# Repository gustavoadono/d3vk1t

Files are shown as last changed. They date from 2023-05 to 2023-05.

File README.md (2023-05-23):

# **d3vkit board**
This repository contains information and resources related to a custom board featuring the STM32F412RET6 microcontroller. This board has been developed for study purposes and includes several integrated components, such as the LSM6DSMTR sensor (accelerometer and gyroscope), the HDC1080DMBR sensor (temperature and humidity), and the LPS22HBTR sensor (barometer). Additionally, the board features an SD card slot, CAN and RS485 interfaces, USB connectivity, and the ESP32-C3-WROOM-02-H4 module for Wi-Fi and Bluetooth communication.

<p align="center">
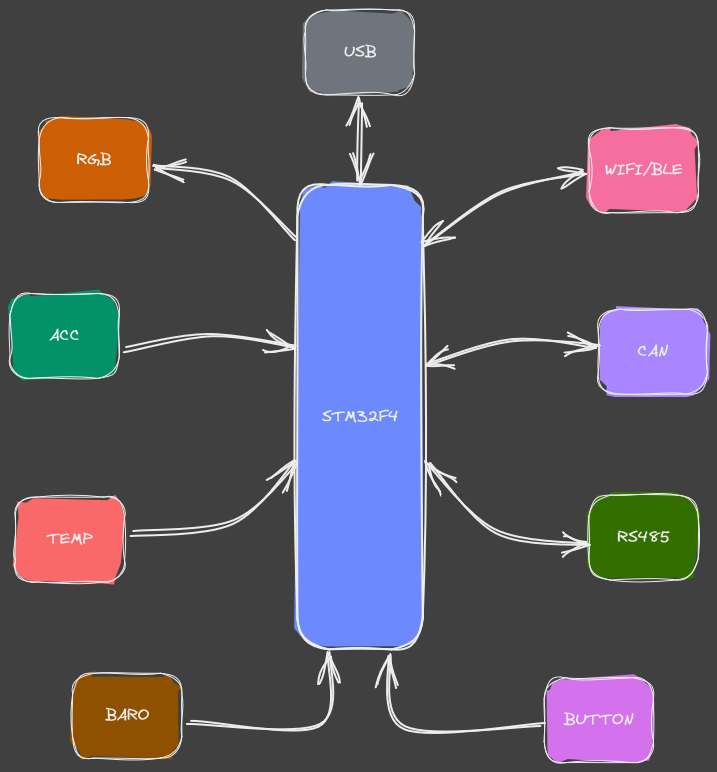
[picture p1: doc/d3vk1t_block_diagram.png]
diagram
  
</p>

# **overview**

The custom board has been designed to provide a flexible platform for studying and experimentation using the STM32F412RET6 microcontroller. It encompasses the following key features:

1. **STM32F412RET6 Microcontroller**: The STM32F412RET6 is a high-performance microcontroller based on the ARM Cortex-M4 architecture. It operates at a clock frequency of up to 100 MHz, with 512 KB of flash memory and 128 KB of RAM. This microcontroller offers advanced features, including peripheral interfaces, ADC, timers, and serial communication.

2. **LSM6DSMTR Sensor (Accelerometer and Gyroscope)**: The board integrates the LSM6DSMTR sensor, which combines a three-axis accelerometer and a three-axis gyroscope. This enables accurate motion detection, acceleration measurement, and inclination sensing.

3. **HDC1080DMBR Sensor (Temperature and Humidity)**: The board includes the HDC1080DMBR sensor, which provides precise temperature and humidity measurements in the surrounding environment. This feature is beneficial for projects involving climate monitoring or environmental control.

4. **LPS22HBTR Sensor (Barometer)**: The board incorporates the LPS22HBTR sensor, allowing atmospheric pressure measurements. This functionality proves useful for projects related to weather monitoring, altitude sensing, or flight control.

5. **SD Card Slot**: The board features an SD card slot, enabling read and write operations with removable memory cards. This facilitates data storage, such as measurement logs or configuration files.

6. **CAN and RS485 Interfaces**: The board incorporates circuits for CAN and RS485 interfaces, widely used in industrial applications for device communication. These interfaces ease integration within automation systems.

7. **USB Connectivity**: The board provides a USB port for communication with a computer or connection to other USB devices. This port supports data transfer and can power the board.

8. **ESP32-C3-WROOM-02-H4 Module (Wi-Fi and Bluetooth)**: The board includes the ESP32-C3-WROOM-02-H4 module, offering Wi-Fi and Bluetooth connectivity. This enables wireless communication, connection to Wi-Fi networks, and interaction with Bluetooth devices, making it suitable for IoT projects.

# **contact**

If you have any questions or need further information, feel free to get in touch. You can reach me via the provided email address in the repository's profile.

# bill of material

you can see the entire bill of materials through this link [d3vk1t-bom](https://gustavoadono.github.io/board/d3vk1t-bom).

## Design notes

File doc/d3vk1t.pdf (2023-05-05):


04/05/2023

d3vk1t Project
Configuration Report

## 1. Description

### 1.1. Project

Project Name | d3vk1t
Board Name | custom
Generated with: | STM32CubeMX 6.8.0
Date | 05/04/2023

### 1.2. MCU

MCU Series | STM32F4
MCU Line | STM32F412
MCU name | STM32F412RETx
MCU Package | LQFP64
MCU Pin number | 64

### 1.3. Core(s) information

Core(s) | Arm Cortex-M4

## 2. Pinout Configuration

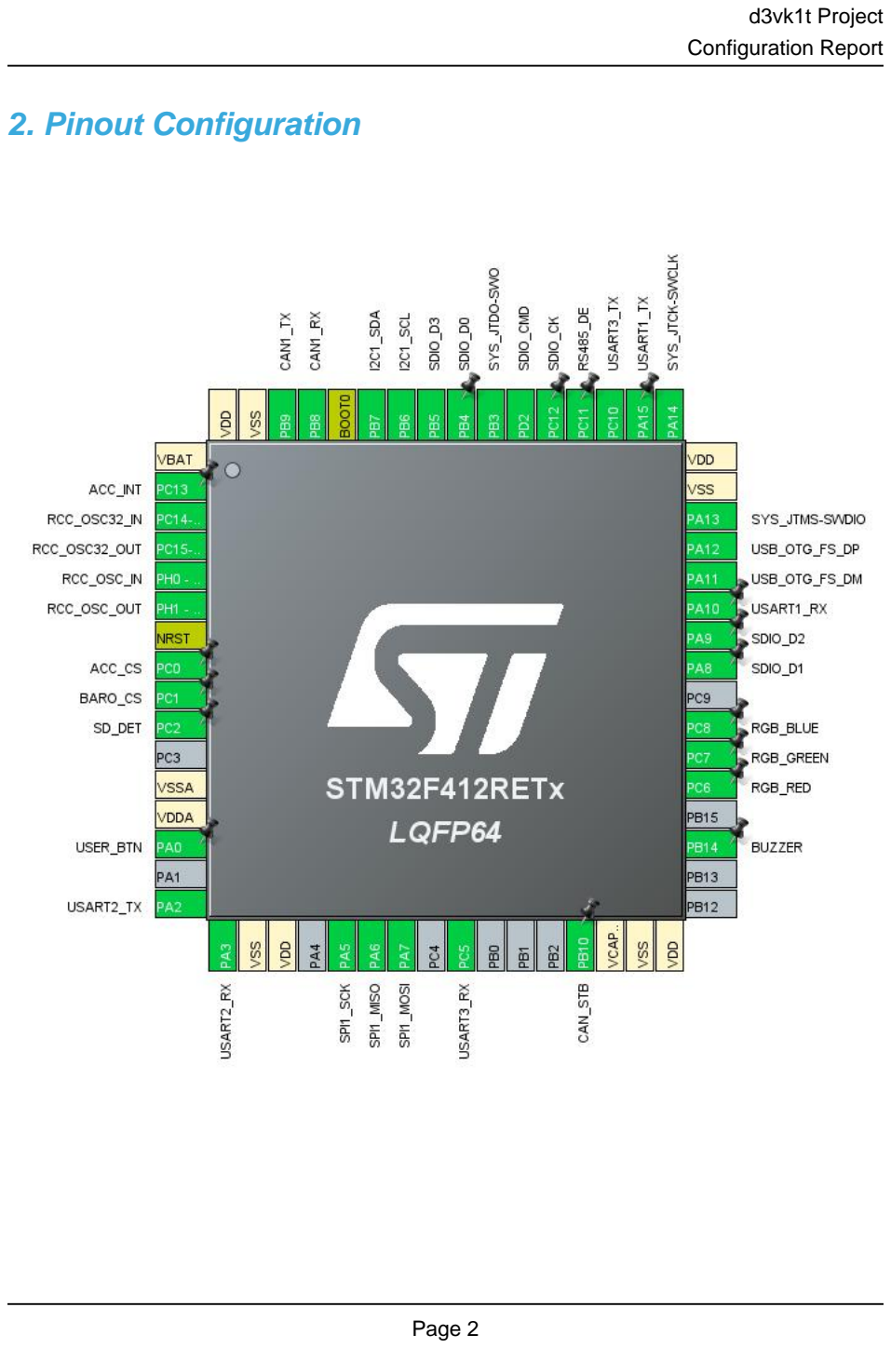
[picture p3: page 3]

## 3. Pins Configuration

Pin Number LQFP64 | Pin Name (function after reset) | Pin Type | Alternate Function(s) | Label
1 | VBAT | Power
2 | PC13 | I/O | GPIO_EXTI13 | ACC_INT
3 | PC14-OSC32_IN | I/O | RCC_OSC32_IN
4 | PC15-OSC32_OUT | I/O | RCC_OSC32_OUT
5 | PH0 - OSC_IN | I/O | RCC_OSC_IN
6 | PH1 - OSC_OUT | I/O | RCC_OSC_OUT
7 | NRST | Reset
8 | PC0 * | I/O | GPIO_Output | ACC_CS
9 | PC1 * | I/O | GPIO_Output | BARO_CS
10 | PC2 | I/O | GPIO_EXTI2 | SD_DET
12 | VSSA | Power
13 | VDDA | Power
14 | PA0 | I/O | GPIO_EXTI0 | USER_BTN
16 | PA2 | I/O | USART2_TX
17 | PA3 | I/O | USART2_RX
18 | VSS | Power
19 | VDD | Power
21 | PA5 | I/O | SPI1_SCK
22 | PA6 | I/O | SPI1_MISO
23 | PA7 | I/O | SPI1_MOSI
25 | PC5 | I/O | USART3_RX
29 | PB10 * | I/O | GPIO_Output | CAN_STB
30 | VCAP_1 | Power
31 | VSS | Power
32 | VDD | Power
35 | PB14 | I/O | TIM12_CH1 | BUZZER
37 | PC6 | I/O | TIM8_CH1 | RGB_RED
38 | PC7 | I/O | TIM8_CH2 | RGB_GREEN
39 | PC8 | I/O | TIM8_CH3 | RGB_BLUE
41 | PA8 | I/O | SDIO_D1
42 | PA9 | I/O | SDIO_D2
43 | PA10 | I/O | USART1_RX
44 | PA11 | I/O | USB_OTG_FS_DM
45 | PA12 | I/O | USB_OTG_FS_DP
46 | PA13 | I/O | SYS_JTMS-SWDIO
47 | VSS | Power

Pin Number LQFP64 | Pin Name (function after reset) | Pin Type | Alternate Function(s) | Label
48 | VDD | Power
49 | PA14 | I/O | SYS_JTCK-SWCLK
50 | PA15 | I/O | USART1_TX
51 | PC10 | I/O | USART3_TX
52 | PC11 * | I/O | GPIO_Output | RS485_DE
53 | PC12 | I/O | SDIO_CK
54 | PD2 | I/O | SDIO_CMD
55 | PB3 | I/O | SYS_JTDO-SWO
56 | PB4 | I/O | SDIO_D0
57 | PB5 | I/O | SDIO_D3
58 | PB6 | I/O | I2C1_SCL
59 | PB7 | I/O | I2C1_SDA
60 | BOOT0 | Boot
61 | PB8 | I/O | CAN1_RX
62 | PB9 | I/O | CAN1_TX
63 | VSS | Power
64 | VDD | Power

* The pin is affected with an I/O function

## 4. Clock Tree Configuration

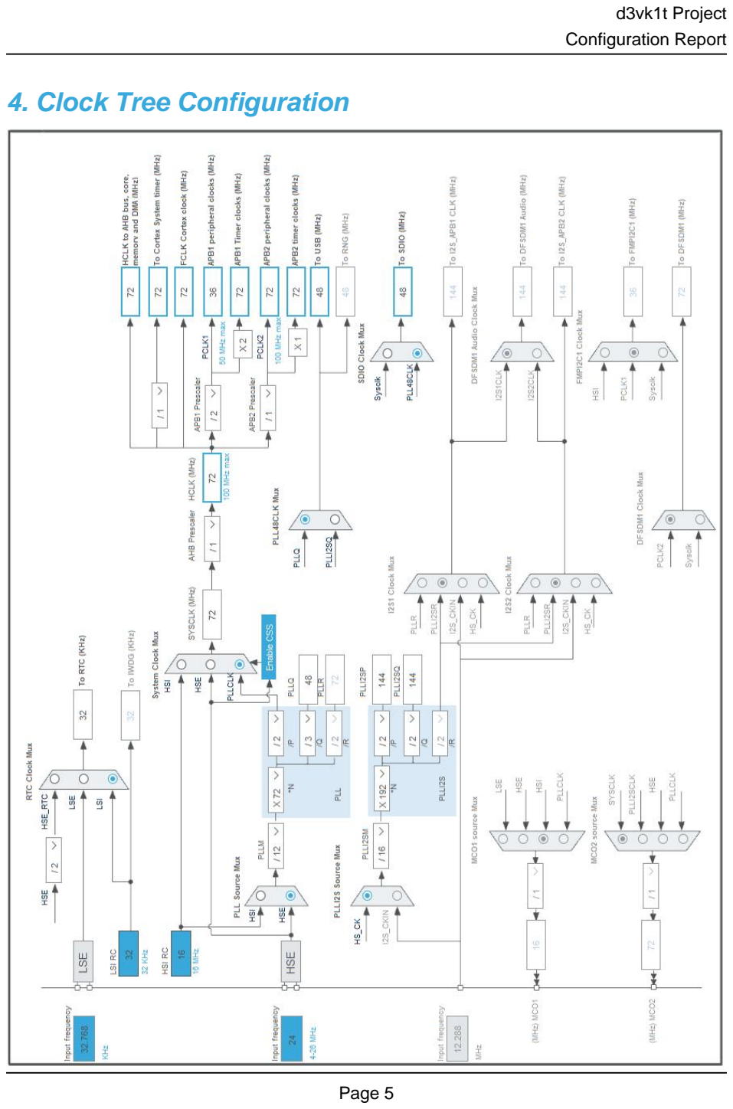
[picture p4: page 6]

## 5. Software Project

### 5.1. Project Settings

Name | Value
Project Name | d3vk1t
Project Folder | C:\dev\personal\hardware\d3vk1t\doc
Toolchain / IDE | EWARM V8.50
Firmware Package Name and Version | STM32Cube FW_F4 V1.27.1
Application Structure | Advanced
Generate Under Root | No
Do not generate the main() | No
Minimum Heap Size | 0x200
Minimum Stack Size | 0x400

### 5.2. Code Generation Settings

Name | Value
STM32Cube MCU packages and embedded software | Copy all used libraries into the project folder
Generate peripheral initialization as a pair of '.c/.h' files | No
Backup previously generated files when re-generating | No
Keep User Code when re-generating | Yes
Delete previously generated files when not re-generated | Yes
Set all free pins as analog (to optimize the power consumption) | No
Enable Full Assert | No

### 5.3. Advanced Settings - Generated Function Calls

Rank | Function Name | Peripheral Instance Name
1 | SystemClock_Config | RCC
2 | MX_GPIO_Init | GPIO
3 | MX_CAN1_Init | CAN1
4 | MX_I2C1_Init | I2C1
5 | MX_SDIO_SD_Init | SDIO
6 | MX_USART1_UART_Init | USART1
7 | MX_USART2_UART_Init | USART2
8 | MX_USB_OTG_FS_PCD_Init | USB_OTG_FS
9 | MX_RTC_Init | RTC
10 | MX_SPI1_Init | SPI1
11 | MX_TIM8_Init | TIM8

Rank | Function Name | Peripheral Instance Name
12 | MX_TIM12_Init | TIM12
13 | MX_USART3_UART_Init | USART3

## 6. Power Consumption Calculator report

### 6.1. Microcontroller Selection

Series | STM32F4
Line | STM32F412
MCU | STM32F412RETx
Datasheet | DS11139_Rev5

### 6.2. Parameter Selection

Temperature | 25
Vdd | 1.7

### 6.3. Battery Selection

Battery | Li-SOCL2(A3400)
Capacity | 3400.0 mAh
Self Discharge | 0.08 %/month
Nominal Voltage | 3.6 V
Max Cont Current | 100.0 mA
Max Pulse Current | 200.0 mA
Cells in series | 1
Cells in parallel | 1

### 6.4. Sequence

Step | Step1 | Step2
Mode | RUN | STOP
Vdd | 1.7 | 1.7
Voltage Source | Battery | Battery
Range | Scale1-High | No Scale
Fetch Type | FLASH | n/a
CPU Frequency | 100 MHz | 0 Hz
Clock Configuration | HSE PLL | Regulator_LPLV Flash-PwrDwn
Clock Source Frequency | 4 MHz | 0 Hz
Peripherals
Additional Cons. | 0 mA | 0 mA
Average Current | 21.7 mA | 18.5 µA
Duration | 0.1 ms | 0.9 ms
DMIPS | 125.0 | 0.0
Ta Max | 103.27 | 105
Category | In DS Table | In DS Table

### 6.5. Results

Sequence Time | 1 ms | Average Current | 2.19 mA
Battery Life | 2 months, 3 days, 20 hours | Average DMIPS | 125.0 DMIPS

### 6.6. Chart

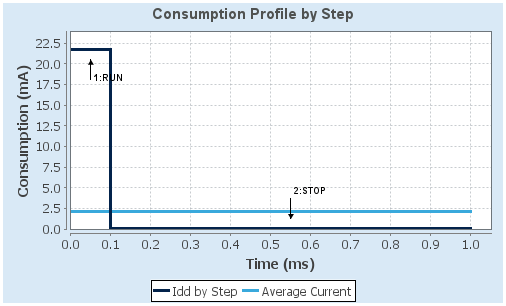
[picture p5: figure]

## 7. Peripherals and Middlewares Configuration

### 7.1. CAN1

mode: Activated
7.1.1. Parameter Settings:

Bit Timings Parameters:

Prescaler (for Time Quantum) | 16
Time Quantum | 444.44444444444446 *
Time Quanta in Bit Segment 1 | 1 Time
Time Quanta in Bit Segment 2 | 1 Time
Time for one Bit | 1333 *
Baud Rate | 749999 *
ReSynchronization Jump Width | 1 Time
Basic Parameters:
Time Triggered Communication Mode | Disable
Automatic Bus-Off Management | Disable
Automatic Wake-Up Mode | Disable
Automatic Retransmission | Disable
Receive Fifo Locked Mode | Disable
Transmit Fifo Priority | Disable
Advanced Parameters:
Operating Mode | Normal

### 7.2. I2C1

I2C: I2C
7.2.1. Parameter Settings:

Master Features:

I2C Speed Mode | Standard Mode
I2C Clock Speed (Hz) | 100000
Slave Features:
Clock No Stretch Mode | Disabled
Primary Address Length selection | 7-bit
Dual Address Acknowledged | Disabled
Primary slave address | 0
General Call address detection | Disabled

### 7.3. RCC

High Speed Clock (HSE): Crystal/Ceramic Resonator Low Speed Clock (LSE) : Crystal/Ceramic Resonator
7.3.1. Parameter Settings:

System Parameters:

VDD voltage (V) | 3.3
Instruction Cache | Enabled
Prefetch Buffer | Enabled
Data Cache | Enabled
Flash Latency(WS) | 2 WS (3 CPU cycle)
RCC Parameters:
HSI Calibration Value | 16
TIM Prescaler Selection | Disabled
HSE Startup Timout Value (ms) | 100
LSE Startup Timout Value (ms) | 5000
Power Parameters:
Power Regulator Voltage Scale | Power Regulator Voltage Scale 1

### 7.4. RTC

mode: Activate Clock Source
7.4.1. Parameter Settings:

General:

Hour Format | Hourformat 24
Asynchronous Predivider value | 127
Synchronous Predivider value | 255

### 7.5. SDIO

Mode: SD 4 bits Wide bus
7.5.1. Parameter Settings:

SDIO parameters:

Clock transition on which the bit capture is made Rising transition

SDIO Clock divider bypass | Disable
SDIO Clock output enable when the bus is idle | Disable the power save for the clock
SDIO hardware flow control | The hardware control flow is disabled
SDIOCLK clock divide factor | 0

### 7.6. SPI1

Mode: Full-Duplex Master
7.6.1. Parameter Settings:

Basic Parameters:

Frame Format | Motorola
Data Size | 8 Bits
First Bit | MSB First
Clock Parameters:
Prescaler (for Baud Rate) | 2
Baud Rate | 36.0 MBits/s *
Clock Polarity (CPOL) | Low
Clock Phase (CPHA) | 1 Edge
Advanced Parameters:
CRC Calculation | Disabled
NSS Signal Type | Software

### 7.7. SYS

Debug: Trace Asynchronous Sw Timebase Source: SysTick

### 7.8. TIM8

Channel1: PWM Generation CH1 Channel2: PWM Generation CH2 Channel3: PWM Generation CH3
7.8.1. Parameter Settings:

Counter Settings:

Prescaler (PSC - 16 bits value) | 0
Counter Mode | Up
Counter Period (AutoReload Register - 16 bits value ) | 65535

Internal Clock Division (CKD) | No Division
Repetition Counter (RCR - 8 bits value) | 0
auto-reload preload | Disable
Trigger Output (TRGO) Parameters:
Master/Slave Mode (MSM bit) | Disable (Trigger input effect not delayed)
Trigger Event Selection | Reset (UG bit from TIMx_EGR)
Break And Dead Time management - BRK Configuration:
BRK State | Disable
BRK Polarity | High
Break And Dead Time management - Output Configuration:
Automatic Output State | Disable
Off State Selection for Run Mode (OSSR) | Disable
Off State Selection for Idle Mode (OSSI) | Disable
Lock Configuration | Off
PWM Generation Channel 1:
Mode | PWM mode 1
Pulse (16 bits value) | 0
Output compare preload | Enable
Fast Mode | Disable
CH Polarity | High
CH Idle State | Reset
PWM Generation Channel 2:
Mode | PWM mode 1
Pulse (16 bits value) | 0
Output compare preload | Enable
Fast Mode | Disable
CH Polarity | High
CH Idle State | Reset
PWM Generation Channel 3:
Mode | PWM mode 1
Pulse (16 bits value) | 0
Output compare preload | Enable
Fast Mode | Disable
CH Polarity | High
CH Idle State | Reset

### 7.9. TIM12

Channel1: PWM Generation CH1
7.9.1. Parameter Settings:

Counter Settings:

Prescaler (PSC - 16 bits value) | 0
Counter Mode | Up
Counter Period (AutoReload Register - 16 bits value ) | 65535
Internal Clock Division (CKD) | No Division
auto-reload preload | Disable
PWM Generation Channel 1:
Mode | PWM mode 1
Pulse (16 bits value) | 0
Output compare preload | Enable
Fast Mode | Disable
CH Polarity | High

### 7.10. USART1

Mode: Asynchronous
7.10.1. Parameter Settings:

Basic Parameters:

Baud Rate | 115200
Word Length | 8 Bits (including Parity)
Parity | None
Stop Bits | 1
Advanced Parameters:
Data Direction | Receive and Transmit
Over Sampling | 16 Samples

### 7.11. USART2

Mode: Asynchronous
7.11.1. Parameter Settings:

Basic Parameters:

Baud Rate | 115200
Word Length | 8 Bits (including Parity)
Parity | None
Stop Bits | 1
Advanced Parameters:

Data Direction | Receive and Transmit
Over Sampling | 16 Samples

### 7.12. USART3

Mode: Asynchronous
7.12.1. Parameter Settings:

Basic Parameters:

Baud Rate | 115200
Word Length | 8 Bits (including Parity)
Parity | None
Stop Bits | 1
Advanced Parameters:
Data Direction | Receive and Transmit
Over Sampling | 16 Samples

### 7.13. USB_OTG_FS

Mode: Device_Only
7.13.1. Parameter Settings:
Speed | Full Speed 12MBit/s
Low power | Disabled
Battery charging | Disabled
Link Power Management | Disabled
VBUS sensing | Disabled
Signal start of frame | Disabled

* User modified value

## 8. System Configuration

### 8.1. GPIO configuration

IP | Pin | Signal | GPIO mode | GPIO pull/up pull down

Max
Speed

User Label

CAN1 | PB8 | CAN1_RX | Alternate Function Push Pull | No pull-up and no pull-down | Very High
*
| PB9 | CAN1_TX | Alternate Function Push Pull | No pull-up and no pull-down | Very High
*
I2C1 | PB6 | I2C1_SCL | Alternate Function Open Drain | No pull-up and no pull-down | Very High
*
| PB7 | I2C1_SDA | Alternate Function Open Drain | No pull-up and no pull-down | Very High
*
RCC | PC14- OSC32_IN | RCC_OSC32_IN | n/a | n/a | n/a
| PC15- OSC32_OU T | RCC_OSC32_O UT | n/a | n/a | n/a

PH0 -
OSC_IN
| | RCC_OSC_IN | n/a | n/a | n/a
| PH1 - OSC_OUT | RCC_OSC_OUT | n/a | n/a | n/a
SDIO | PA8 | SDIO_D1 | Alternate Function Push Pull | No pull-up and no pull-down | Very High
| PA9 | SDIO_D2 | Alternate Function Push Pull | No pull-up and no pull-down | Very High
| PC12 | SDIO_CK | Alternate Function Push Pull | No pull-up and no pull-down | Very High
| PD2 | SDIO_CMD | Alternate Function Push Pull | No pull-up and no pull-down | Very High
| PB4 | SDIO_D0 | Alternate Function Push Pull | No pull-up and no pull-down | Very High
| PB5 | SDIO_D3 | Alternate Function Push Pull | No pull-up and no pull-down | Very High
SPI1 | PA5 | SPI1_SCK | Alternate Function Push Pull | No pull-up and no pull-down | Very High
*
| PA6 | SPI1_MISO | Alternate Function Push Pull | No pull-up and no pull-down | Very High
*
| PA7 | SPI1_MOSI | Alternate Function Push Pull | No pull-up and no pull-down | Very High
*
SYS | PA13 | SYS_JTMS- SWDIO | n/a | n/a | n/a
| PA14 | SYS_JTCK- SWCLK | n/a | n/a | n/a
| PB3 | SYS_JTDO- SWO | n/a | n/a | n/a
TIM8 | PC6 | TIM8_CH1 | Alternate Function Push Pull | No pull-up and no pull-down | Low | RGB_RED

IP | Pin | Signal | GPIO mode | GPIO pull/up pull down | Max Speed | User Label
| PC7 | TIM8_CH2 | Alternate Function Push Pull | No pull-up and no pull-down | Low | RGB_GREEN
| PC8 | TIM8_CH3 | Alternate Function Push Pull | No pull-up and no pull-down | Low | RGB_BLUE
TIM12 | PB14 | TIM12_CH1 | Alternate Function Push Pull | No pull-up and no pull-down | Low | BUZZER
USART1 | PA10 | USART1_RX | Alternate Function Push Pull | No pull-up and no pull-down | Very High *
| PA15 | USART1_TX | Alternate Function Push Pull | No pull-up and no pull-down | Very High *
USART2 | PA2 | USART2_TX | Alternate Function Push Pull | No pull-up and no pull-down | Very High *
| PA3 | USART2_RX | Alternate Function Push Pull | No pull-up and no pull-down | Very High *
USART3 | PC5 | USART3_RX | Alternate Function Push Pull | No pull-up and no pull-down | Very High *
| PC10 | USART3_TX | Alternate Function Push Pull | No pull-up and no pull-down | Very High *
USB_OTG_ FS | PA11 | USB_OTG_FS_ DM | Alternate Function Push Pull | No pull-up and no pull-down | Very High *
| PA12 | USB_OTG_FS_ DP | Alternate Function Push Pull | No pull-up and no pull-down | Very High *
GPIO | PC13 | GPIO_EXTI13 | External Interrupt Mode with Rising edge trigger detection | No pull-up and no pull-down | n/a | ACC_INT
| PC0 | GPIO_Output | Output Push Pull | No pull-up and no pull-down | Low | ACC_CS
| PC1 | GPIO_Output | Output Push Pull | No pull-up and no pull-down | Low | BARO_CS
| PC2 | GPIO_EXTI2 | External Interrupt Mode with Rising edge trigger detection | No pull-up and no pull-down | n/a | SD_DET
| PA0 | GPIO_EXTI0 | External Interrupt Mode with Rising edge trigger detection | No pull-up and no pull-down | n/a | USER_BTN
| PB10 | GPIO_Output | Output Push Pull | No pull-up and no pull-down | Low | CAN_STB
| PC11 | GPIO_Output | Output Push Pull | No pull-up and no pull-down | Low | RS485_DE

### 8.2. DMA configuration

nothing configured in DMA service

### 8.3. NVIC configuration

8.3.1. NVIC
Interrupt Table | Enable | Preenmption Priority | SubPriority
Non maskable interrupt | true | 0 | 0
Hard fault interrupt | true | 0 | 0
Memory management fault | true | 0 | 0
Pre-fetch fault, memory access fault | true | 0 | 0
Undefined instruction or illegal state | true | 0 | 0
System service call via SWI instruction | true | 0 | 0
Debug monitor | true | 0 | 0
Pendable request for system service | true | 0 | 0
System tick timer | true | 15 | 0
PVD interrupt through EXTI line 16 | | unused
Flash global interrupt | | unused
RCC global interrupt | | unused
EXTI line0 interrupt | | unused
EXTI line2 interrupt | | unused
CAN1 TX interrupts | | unused
CAN1 RX0 interrupts | | unused
CAN1 RX1 interrupt | | unused
CAN1 SCE interrupt | | unused
I2C1 event interrupt | | unused
I2C1 error interrupt | | unused
SPI1 global interrupt | | unused
USART1 global interrupt | | unused
USART2 global interrupt | | unused
USART3 global interrupt | | unused
EXTI line[15:10] interrupts | | unused
TIM8 break interrupt and TIM12 global interrupt | | unused
TIM8 update interrupt and TIM13 global interrupt | | unused
TIM8 trigger and commutation interrupts and TIM14 global interrupt | | unused
TIM8 capture compare interrupt | | unused
SDIO global interrupt | | unused
USB On The Go FS global interrupt | | unused
FPU global interrupt | | unused
8.3.2. NVIC Code generation
Enabled interrupt Table | Select for init | Generate IRQ | Call HAL handler

Enabled interrupt Table | Select for init sequence ordering | Generate IRQ handler | Call HAL handler
Non maskable interrupt | false | true | false
Hard fault interrupt | false | true | false
Memory management fault | false | true | false
Pre-fetch fault, memory access fault | false | true | false
Undefined instruction or illegal state | false | true | false
System service call via SWI instruction | false | true | false
Debug monitor | false | true | false
Pendable request for system service | false | true | false
System tick timer | false | true | true

* User modified value

## 9. System Views

9.1. Category view
9.1.1. Current

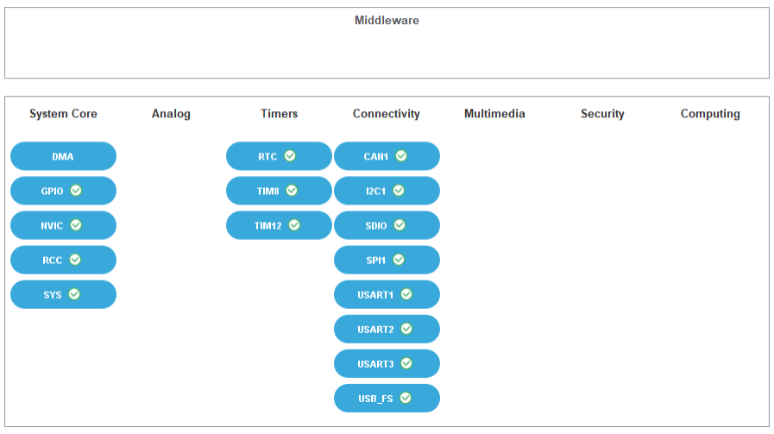
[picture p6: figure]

## 10. Docs & Resources

Type | Link
BSDL files | https://www.st.com/resource/en/bsdl_model/stm32f412_bsdl.zip
IBIS models | https://www.st.com/resource/en/ibis_model/stm32f412_ibis.zip
System View Description | https://www.st.com/resource/en/svd/stm32f4_svd.zip
BSDL files | https://www.st.com/resource/en/bsdl_model/stm32f412_bsdl.zip
IBIS models | https://www.st.com/resource/en/ibis_model/stm32f412_ibis.zip
System View Description | https://www.st.com/resource/en/svd/stm32f4_svd.zip
Presentations | https://www.st.com/resource/en/product_presentation/stm32-stm8_embedded_software_solutions.pdf
Presentations | https://www.st.com/resource/en/product_presentation/stm32_eval-tools_portfolio.pdf
Presentations | https://www.st.com/resource/en/product_presentation/stm32_stm8_functi onal-safety-packages.pdf
Presentations | https://www.st.com/resource/en/product_presentation/stm32-stm8_software_development_tools.pdf
Training Material | https://www.st.com/resource/en/sales_guide/sg_sc2154.pdf
Flyers | https://www.st.com/resource/en/flyer/flstm32f4x1.pdf
Flyers | https://www.st.com/resource/en/flyer/flstm32nucleo.pdf
Flyers | https://www.st.com/resource/en/flyer/flstmcsuite.pdf
Flyers | https://www.st.com/resource/en/flyer/flstm32trust.pdf
Product Certifications | https://www.st.com/resource/en/certification_document/stm32_authentication_can.pdf
Application Notes | https://www.st.com/resource/en/application_note/an1181-electrostatic-discharge-sensitivity-measurement-stmicroelectronics.pdf
Application Notes | https://www.st.com/resource/en/application_note/an1709-emc-design-guide-for-stm8-stm32-and-legacy-mcus-stmicroelectronics.pdf
Application Notes | https://www.st.com/resource/en/application_note/an2606-stm32-

| microcontroller-system-memory-boot-mode-stmicroelectronics.pdf
Application Notes | https://www.st.com/resource/en/application_note/an2639-soldering-recommendations-and-package-information-for-leadfree-ecopack-mcus-and-mpus-stmicroelectronics.pdf
Application Notes | https://www.st.com/resource/en/application_note/an2834-how-to-get-the-best-adc-accuracy-in-stm32-microcontrollers-stmicroelectronics.pdf
Application Notes | https://www.st.com/resource/en/application_note/an2867-oscillator-design-guide-for-stm8afals-stm32-mcus-and-mpus-stmicroelectronics.pdf
Application Notes | https://www.st.com/resource/en/application_note/an2945-stm8s-and-stm32-mcus-a-consistent-832bit-product-line-for-painless-migration-stmicroelectronics.pdf
Application Notes | https://www.st.com/resource/en/application_note/an3070-managing-the-driver-enable-signal-for-rs485-and-iolink-communications-with-the-stm32s-usart-stmicroelectronics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
Application Notes | https://www.st.com/resource/en/application_note/an3126-audio-and-waveform-generation-using-the-dac-in-stm32-products-stmicroelectronics.pdf
Application Notes | https://www.st.com/resource/en/application_note/an3154-can-protocol-used-in-the-stm32-bootloader-stmicroelectronics.pdf
Application Notes | https://www.st.com/resource/en/application_note/an3155-usart-protocol-used-in-the-stm32-bootloader-stmicroelectronics.pdf
Application Notes | https://www.st.com/resource/en/application_note/an3156-usb-dfu-protocol-used-in-the-stm32-bootloader-stmicroelectronics.pdf
Application Notes | https://www.st.com/resource/en/application_note/an3364-migration-and-compatibility-guidelines-for-stm32-microcontroller-applications-stmicroelectronics.pdf
Application Notes | https://www.st.com/resource/en/application_note/an3997-audio-playback-and-recording-using-the-stm32f4discovery-stmicroelectronics.pdf
Application Notes | https://www.st.com/resource/en/application_note/an3998-pdm-audio-software-decoding-on-stm32-microcontrollers-stmicroelectronics.pdf
Application Notes | https://www.st.com/resource/en/application_note/an4013-stm32-crossseries-timer-overview-stmicroelectronics.pdf
Application Notes | https://www.st.com/resource/en/application_note/an4031-using-the-

| stm32f2-stm32f4-and-stm32f7-series-dma-controller-stmicroelectronics.pdf
Application Notes | https://www.st.com/resource/en/application_note/an4221-i2c-protocol-used-in-the-stm32-bootloader-stmicroelectronics.pdf
Application Notes | https://www.st.com/resource/en/application_note/an4229-how-to-implement-a-vocoder-solution-using-stm32-microcontrollers-stmicroelectronics.pdf
Application Notes | https://www.st.com/resource/en/application_note/an4230-stm32-microcontroller-random-number-generation-validation-using-the-nist-statistical-test-suite-stmicroelectro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
Application Notes | https://www.st.com/resource/en/application_note/an4277-using-stm32-device-pwm-shutdown-features-for-motor-control-and-digital-power-conversion-stmicroelectronics.pdf
Application Notes | https://www.st.com/resource/en/application_note/an4286-spi-protocol-used-in-the-stm32-bootloader-stmicroelectronics.pdf
Application Notes | https://www.st.com/resource/en/application_note/an4488-getting-started-with-stm32f4xxxx-mcu-hardware-development-stmicroelectronics.pdf
Application Notes | https://www.st.com/resource/en/application_note/an4566-extending-the-dac-performance-of-stm32-microcontrollers-stmicroelectronics.pdf
Application Notes | https://www.st.com/resource/en/application_note/an4655-virtually-increasing-the-number-of-serial-communication-peripherals-in-stm32-applications-stmicroelectronics.p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
Application Notes | https://www.st.com/resource/en/application_note/an4739-stm32cube-firmware-examples-for-stm32f4-series-stmicroelectronics.pdf
Application Notes | https://www.st.com/resource/en/application_note/an4750-handling-of-soft-errors-in-stm32-applications-stmicroelectronics.pdf
Application Notes | https://www.st.com/resource/en/application_note/an4759-using-the-hardware-realtime-clock-rtc-and-the-tamper-management-unit-tamp-with-stm32-microcontrollers-stmicroe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
Application Notes | https://www.st.com/resource/en/application_note/an4776-generalpurpose-timer-cookbook-for-stm32-microcontrollers-stmicroelectronics.pdf
Application Notes | https://www.st.com/resource/en/application_note/an4803-highspeed-si- simulations-using-ibis-and-boardlevel-simulations-using-hyperlynx-si-on-

| stm32-mcus-and-mpus-stmicroelectronics.pdf
Application Notes | https://www.st.com/resource/en/application_note/an4838-managing-memory-protection-unit-in-stm32-mcus-stmicroelectronics.pdf
Application Notes | https://www.st.com/resource/en/application_note/an4850-stm32-mcus-spreadspectrum-clock-generation-principles-properties-and-implementation-stmicroelectronics.pdf
Application Notes | https://www.st.com/resource/en/application_note/an4879-usb-hardware-and-pcb-guidelines-using-stm32-mcus-stmicroelectronics.pdf
Application Notes | https://www.st.com/resource/en/application_note/an4904-migration-of-microcontroller-applications-from-stm32f1-series-to-stm32f4-access-lines-stmicroelectronics.pdf
Application Notes | https://www.st.com/resource/en/application_note/an4908-stm32-usart-automatic-baud-rate-detection-stmicroelectronics.pdf
Application Notes | https://www.st.com/resource/en/application_note/an4989-stm32-microcontroller-debug-toolbox-stmicroelectronics.pdf
Application Notes | https://www.st.com/resource/en/application_note/an4990-getting-started-with-sigmadelta-digital-interface-on-applicable-stm32-microcontrollers-stmicroelectronics.pdf
Application Notes | https://www.st.com/resource/en/application_note/an4995-using-an-electromyogram-technique-to-detect-muscle-activity-stmicroelectronics.pdf
Application Notes | https://www.st.com/resource/en/application_note/an5027-interfacing-pdm-digital-microphones-using-stm32-mcus-and-mpus-stmicroelectronics.pdf
Application Notes | https://www.st.com/resource/en/application_note/an5036-thermal-management-guidelines-for-stm32-applications-stmicroelectronics.pdf
Application Notes | https://www.st.com/resource/en/application_note/an5073-receiving-spdif-audio-stream-with-the-stm32f4f7h7-series-stmicroelectronics.pdf
Application Notes | https://www.st.com/resource/en/application_note/an5225-usb-typec-power-delivery-using-stm32-mcus-and-mpus-stmicroelectronics.pdf
Application Notes | https://www.st.com/resource/en/application_note/an5543-enhanced-methods-to-handle-spi-communication-on-stm32-devices-stmicroelectronics.pdf
Application Notes | https://www.st.com/resource/en/application_note/an4760-quadspi-

| interface-on-stm32-microcontrollers-and-microprocessors--stmicroelectronics.pdf
Application Notes | https://www.st.com/resource/en/application_note/an4899-stm32-microcontroller-gpio-hardware-settings-and-lowpower-consumption-stmicroelectronics.pdf
Application Notes | https://www.st.com/resource/en/application_note/an5612-esd-protection-of-stm32-mcus-and-mpus-stmicroelectronics.pdf
Application Notes | https://www.st.com/resource/en/application_note/an5156-introduction-to-stm32-microcontrollers-security-stmicroelectronics.pdf
Application Notes for related Tools & Software | https://www.st.com/resource/en/application_note/an1202_freertos_guide-freertos-guide-stmicroelectronics.pdf
Application Notes for related Tools & Software | https://www.st.com/resource/en/application_note/an1602_semihosting_in_truestudio-how-to-do-semihosting-in-truestudio-stmicroelectronics.pdf
Application Notes for related Tools & Software | https://www.st.com/resource/en/application_note/an1801_stm32cubeprogrammer_in_truestudio-installing-stm32cubeprogrammer-in-truestudio-stmicroelectronics.pdf
Application Notes for related Tools & Software | https://www.st.com/resource/en/application_note/atollic_editing_keyboard_shortcuts-atollic-editing-keyboard-shortcuts-stmicroelectronics.pdf
Application Notes for related Tools & Software | https://www.st.com/resource/en/application_note/iar_to_atollic_truestudio_migration_guide-truestudio-for-arm-migration-guide-iar-embedded-workbench-to-truestudio-stm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
Application Notes for related Tools & Software | https://www.st.com/resource/en/application_note/stm32cubemx_installation_in_truestudio-stm32cubemx-installation-in-truestudio-stmicroelectronics.pdf
Application Notes for related Tools & Software | https://www.st.com/resource/en/application_note/an2656-stm32f10xxx-lcd-glass-driver-firmware-stmicroelectronics.pdf
Application Notes for related Tools & Software | https://www.st.com/resource/en/application_note/an2790-tft-lcd-interfacing-with-the-highdensity-stm32f10xxx-fsmc-stmicroelectronics.pdf
Application Notes | https://www.st.com/resource/en/application_note/an3078-stm32-

for related Tools & Software | inapplication-programming-over-the-ic-bus-stmicroelectronics.pdf
Application Notes for related Tools & Software | https://www.st.com/resource/en/application_note/an3116-stm32s-adc-modes-and-their-applications-stmicroelectronics.pdf
Application Notes for related Tools & Software | https://www.st.com/resource/en/application_note/an3174-implementing-receivers-for-infrared-remote-control-protocols-using-stm32f10xxx-microcontrollers-stmicroelectro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
Application Notes for related Tools & Software | https://www.st.com/resource/en/application_note/an3241-qvga-tftlcd-direct-drive-using-the-stm32f10xx-fsmc-peripheral-stmicroelectronics.pdf
Application Notes for related Tools & Software | https://www.st.com/resource/en/application_note/an3307-guidelines-for-obtaining-iec-60335-class-b-certification-for-any-stm32-application-stmicroelectronics.pdf
Application Notes for related Tools & Software | https://www.st.com/resource/en/application_note/an3364-migration-and-compatibility-guidelines-for-stm32-microcontroller-applications-stmicroelectronics.pdf
Application Notes for related Tools & Software | https://www.st.com/resource/en/application_note/an3965-stm32f40xstm32f41x-inapplication-programming-using-the-usart-stmicroelectronics.pdf
Application Notes for related Tools & Software | https://www.st.com/resource/en/application_note/an3969-eeprom-emulation-in-stm32f40xstm32f41x-microcontrollers-stmicroelectronics.pdf
Application Notes for related Tools & Software | https://www.st.com/resource/en/application_note/an3990-upgrading-stm32f4discovery-board-firmware-using-a-usb-key-stmicroelectronics.pdf
Application Notes for related Tools & Software | https://www.st.com/resource/en/application_note/an3997-audio-playback-and-recording-using-the-stm32f4discovery-stmicroelectronics.pdf
Application Notes for related Tools & Software | https://www.st.com/resource/en/application_note/an3998-pdm-audio-software-decoding-on-stm32-microcontrollers-stmicroelectronics.pdf

Application Notes
for related Tools

https://www.st.com/resource/en/application_note/an4044-floating-pointunit-demonstration-on-stm32-microcontrollers-stmicroelectronics.pdf

& Software
Application Notes for related Tools & Software | https://www.st.com/resource/en/application_note/an4323-getting-started-with-stemwin-library-stmicroelectronics.pdf
Application Notes for related Tools & Software | https://www.st.com/resource/en/application_note/an4435-guidelines-for-obtaining-ulcsaiec-607301603351-class-b-certification-in-any-stm32-application-stmicroelectroni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
Application Notes for related Tools & Software | https://www.st.com/resource/en/application_note/an4457-implementing-an-emulated-uart-on-stm32f4-microcontrollers-stmicroelectronics.pdf
Application Notes for related Tools & Software | https://www.st.com/resource/en/application_note/an4499-stm32--nrf51822-bluetooth-low-energy-system-solution-stmicroelectronics.pdf
Application Notes for related Tools & Software | https://www.st.com/resource/en/application_note/an4502-stm32-smbuspmbus-embedded-software-expansion-for-stm32cube-stmicroelectronics.pdf
Application Notes for related Tools & Software | https://www.st.com/resource/en/application_note/an4515-using-batch-acquisition-mode-bam-to-maximize-power-efficiency-on-stm32f410-stm32f411-stm32f412-stm32f413-micro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
Application Notes for related Tools & Software | https://www.st.com/resource/en/application_note/an4657-stm32-inapplication-programming-iap-using-the-usart-stmicroelectronics.pdf
Application Notes for related Tools & Software | https://www.st.com/resource/en/application_note/an4666-parallel-synchronous-transmission-using-gpio-and-dma-stmicroelectronics.pdf
Application Notes for related Tools & Software | https://www.st.com/resource/en/application_note/an4678-full-duplex-spi-emulation-for-stm32f4-microcontrollers-stmicroelectronics.pdf
Application Notes for related Tools & Software | https://www.st.com/resource/en/application_note/an4701-proprietary-code-readout-protection-on-microcontrollers-of-the-stm32f4-series-stmicroelectronics.pdf

Application Notes
for related Tools

https://www.st.com/resource/en/application_note/an4739-stm32cubefirmware-examples-for-stm32f4-series-stmicroelectronics.pdf

& Software
Application Notes for related Tools & Software | https://www.st.com/resource/en/application_note/an4758-proprietary-code-readout-protection-on-stm32l4-stm32l4-stm32g4-and-stm32wb-series-mcus-stmicroelectronics.pdf
Application Notes for related Tools & Software | https://www.st.com/resource/en/application_note/an4759-using-the-hardware-realtime-clock-rtc-and-the-tamper-management-unit-tamp-with-stm32-microcontrollers-stmicroe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
Application Notes for related Tools & Software | https://www.st.com/resource/en/application_note/an4841-digital-signal-processing-for-stm32-microcontrollers-using-cmsis-stmicroelectronics.pdf
Application Notes for related Tools & Software | https://www.st.com/resource/en/application_note/an4968-proprietary-code-read-out-protection-pcrop-on-stm32f72xxx-and-stm32f73xxx-microcontrollers-stmicroelectronics.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
Application Notes for related Tools & Software | https://www.st.com/resource/en/application_note/an5054-secure-programming-using-stm32cubeprogrammer-stmicroelectronics.pdf
Application Notes for related Tools & Software | https://www.st.com/resource/en/application_note/an5056-integration-guide-for-the-xcubesbsfu-stm32cube-expansion-package-stmicroelectronics.pdf
Application Notes for related Tools & Software | https://www.st.com/resource/en/application_note/an5360-getting-started-with-projects-based-on-the-stm32mp1-series-in-stm32cubeide-stmicroelectronics.pdf
Application Notes for related Tools & Software | https://www.st.com/resource/en/application_note/an5361-getting-started-with-projects-based-on-dualcore-stm32h7-microcontrollers-in-stm32cubeide-stmicroelectronics.pd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
Application Notes for related Tools & Software | https://www.st.com/resource/en/application_note/an5394-getting-started-with-projects-based-on-the-stm32l5-series-in-stm32cubeide-stmicroelectronics.pdf
Application Notes for related Tools & Software | https://www.st.com/resource/en/application_note/an5418-how-to-build-a-simple-usbpd-sink-application-with-stm32cubemx-stmicroelectronics.pdf
Application Notes for related Tools & Software | https://www.st.com/resource/en/application_note/an5426-migrating-graphics-middleware-projects-from-stm32cubemx-540-to-stm32cubemx-550-stmicroelectronics.pdf

Application Notes for related Tools & Software | https://www.st.com/resource/en/application_note/an5464-position-control-of-a-threephase-permanent-magnet-motor-using-xcubemcsdk-or-xcubemcsdkful-stmicroelectronics.p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
Application Notes for related Tools & Software | https://www.st.com/resource/en/application_note/an5564-getting-started-with-projects-based-on-dualcore-stm32wl-microcontrollers-in-stm32cubeide-stmicroelectronics.pd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
Application Notes for related Tools & Software | https://www.st.com/resource/en/application_note/an5698-adapting-the-xcubestl-functional-safety-package-for-stm32-iec-61508-compliant-to-other-safety-standards-stmicr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
Application Notes for related Tools & Software | https://www.st.com/resource/en/application_note/an5731-stm32cubemx-and-stm32cubeide-threadsafe-solution-stmicroelectronics.pdf
Design Notes & Tips | https://www.st.com/resource/en/design_tip/dt0117-microphone-array-beamforming-in-the-pcm-and-pdm-domain-stmicroelectronics.pdf
Device Option Lists | https://www.st.com/resource/en/device_option_list/opl_stm32f412_1m.zip
Errata Sheets | https://www.st.com/resource/en/errata_sheet/es0305-stm32f412xexg-device-limitations-stmicroelectronics.pdf
Datasheet | https://www.st.com/resource/en/datasheet/dm00213872.pdf
Data brief | https://www.st.com/resource/en/data_brief/dm00166585.pdf
Programming Manuals | https://www.st.com/resource/en/programming_manual/pm0214-stm32-cortexm4-mcus-and-mpus-programming-manual-stmicroelectronics.pdf
Reference Manuals | https://www.st.com/resource/en/reference_manual/rm0402-stm32f412-advanced-armbased-32bit-mcus-stmicroelectronics.pdf
Technical Notes & Articles | https://www.st.com/resource/en/technical_note/tn0516-overview-of-the-stm32f0xf100xxf103xx-and-stm32f2xxf30xf4xx-mcus-pmsm-singledual-foc-sdk-v40-stmicroelectronics.p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
Technical Notes & Articles | https://www.st.com/resource/en/technical_note/tn1163-description-of-wlcsp-for-microcontrollers-and-recommendations-for-its-use-stmicroelectronics.pdf
Technical Notes & Articles | https://www.st.com/resource/en/technical_note/tn1204-tape-and-reel-shipping-media-for-stm32-microcontrollers-in-bga-packages-stmicroelectronics.pdf

Technical Notes & Articles | https://www.st.com/resource/en/technical_note/tn1205-tape-and-reel-shipping-media-for-stm8-and-stm32-microcontrollers-in-fpn-packages-stmicroelectronics.pdf
Technical Notes & Articles | https://www.st.com/resource/en/technical_note/tn1206-tape-and-reel-shipping-media-for-stm8-and-stm32-microcontrollers-in-qfp-packages-stmicroelectronics.pdf
Technical Notes & Articles | https://www.st.com/resource/en/technical_note/tn1207-tape-and-reel-shipping-media-for-stm8-and-stm32-microcontrollers-in-so-packages-stmicroelectronics.pdf
Technical Notes & Articles | https://www.st.com/resource/en/technical_note/tn1208-tape-and-reel-shipping-media-for-stm8-and-stm32-microcontrollers-in-tssop-and-ssop-packages-stmicroelectronics.p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
Technical Notes & Articles | https://www.st.com/resource/en/technical_note/tn1433-reference-device-marking-schematics-for-stm32-microcontrollers-and-microprocessors-stmicroelectronics.pdf

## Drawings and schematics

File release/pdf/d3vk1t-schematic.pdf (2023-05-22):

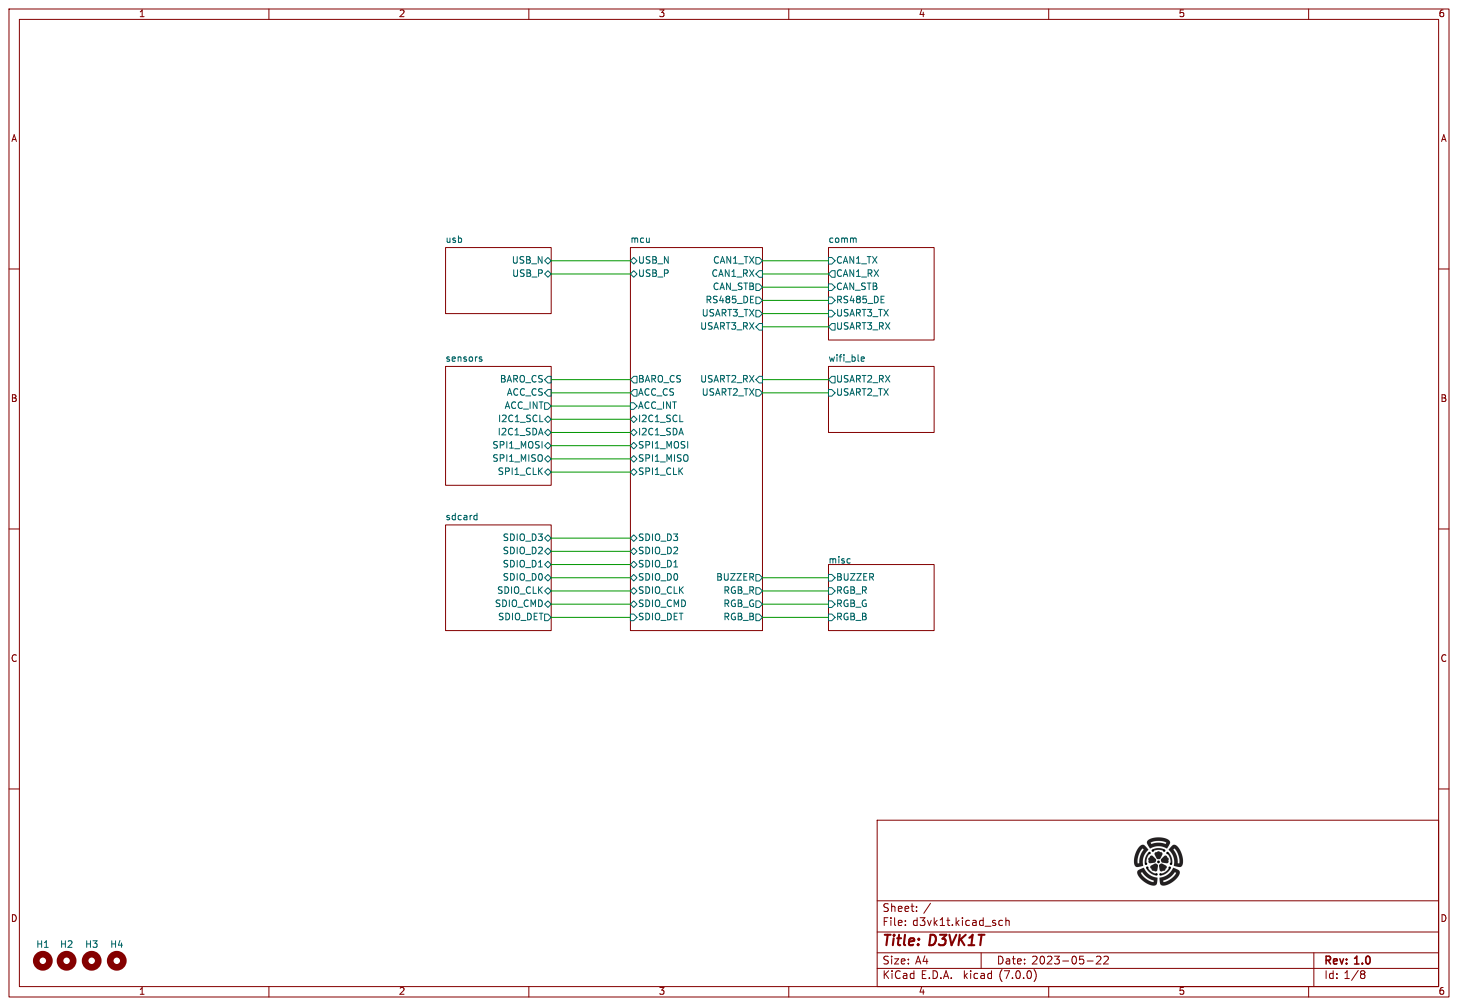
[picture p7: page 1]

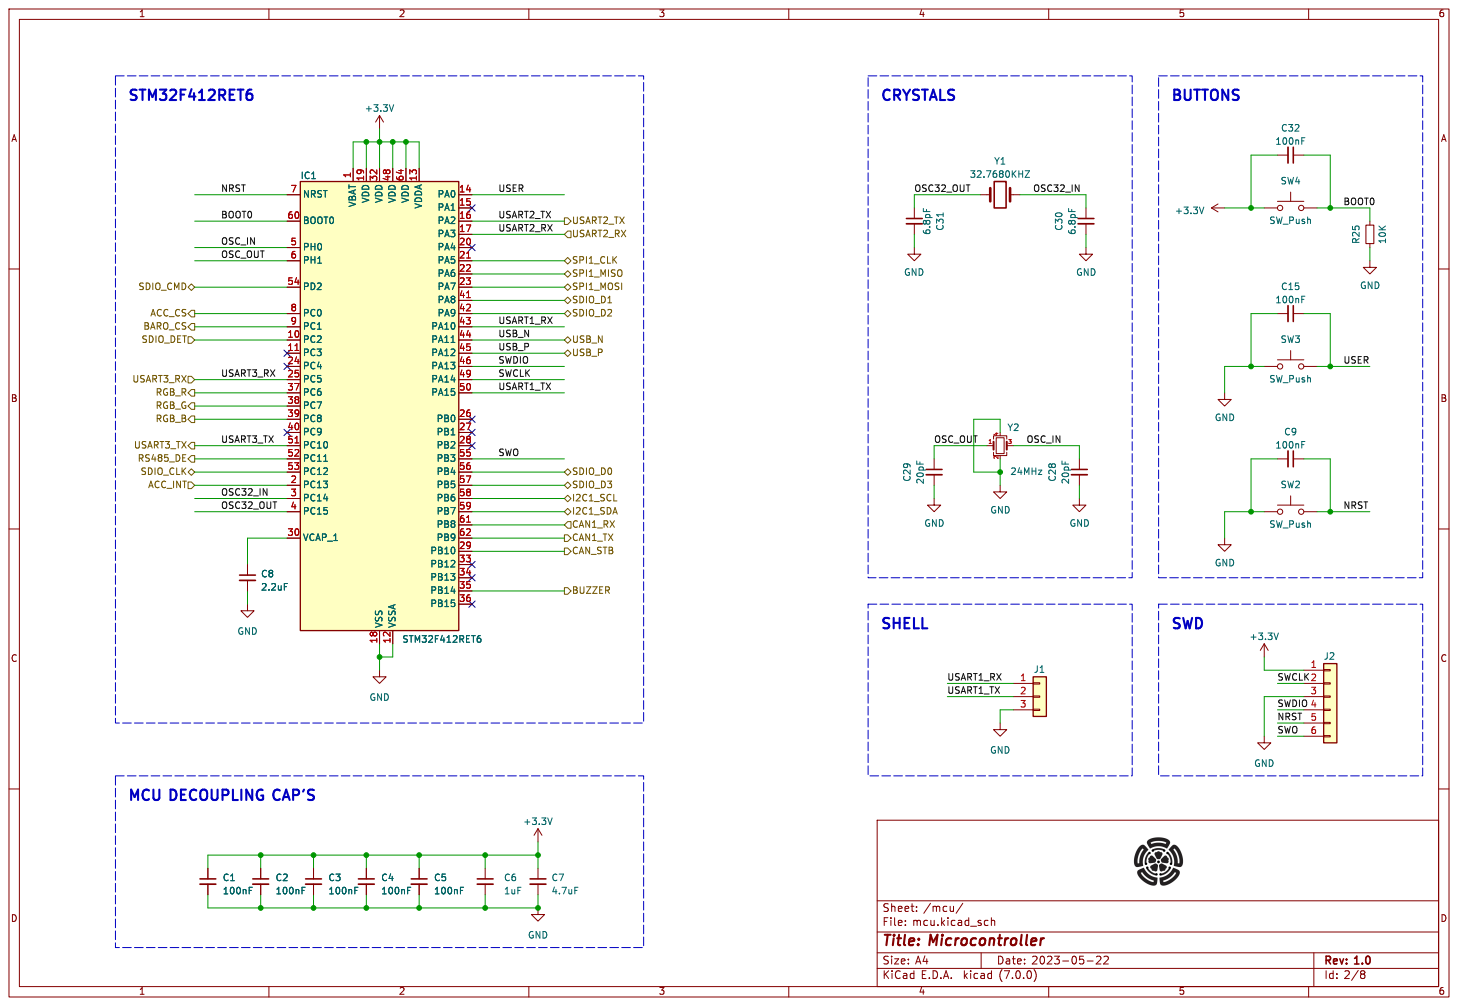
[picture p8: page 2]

Id: 2/8 Title: Microcontroller File: mcu.kicad_sch Sheet: /mcu/

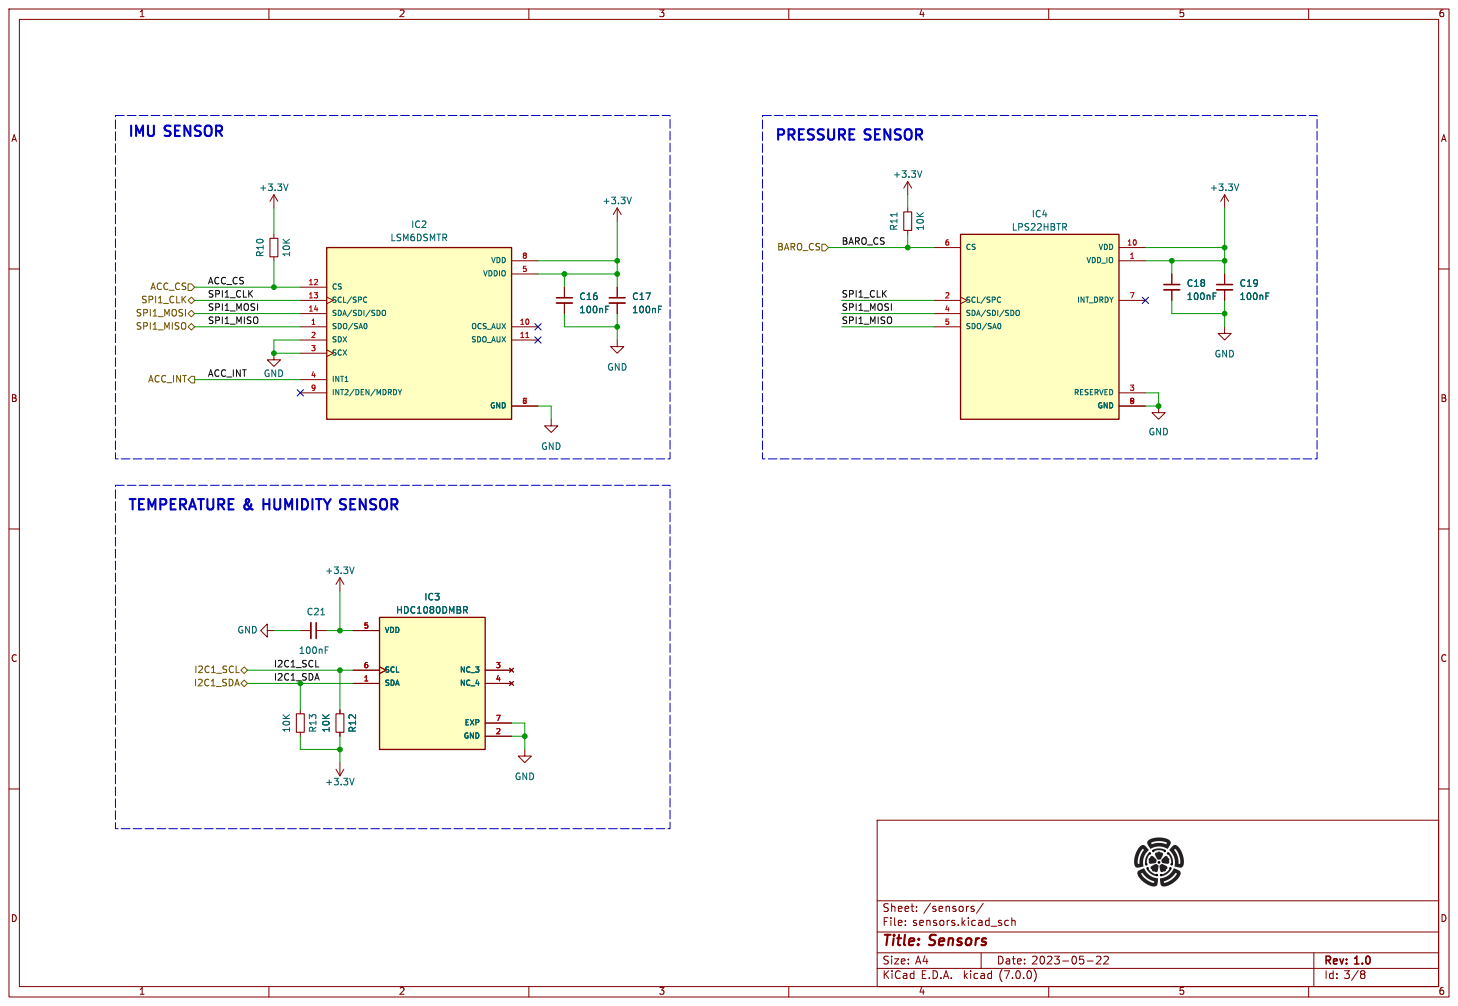
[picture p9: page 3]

File: sensors.kicad_sch Sheet: /sensors/ C21

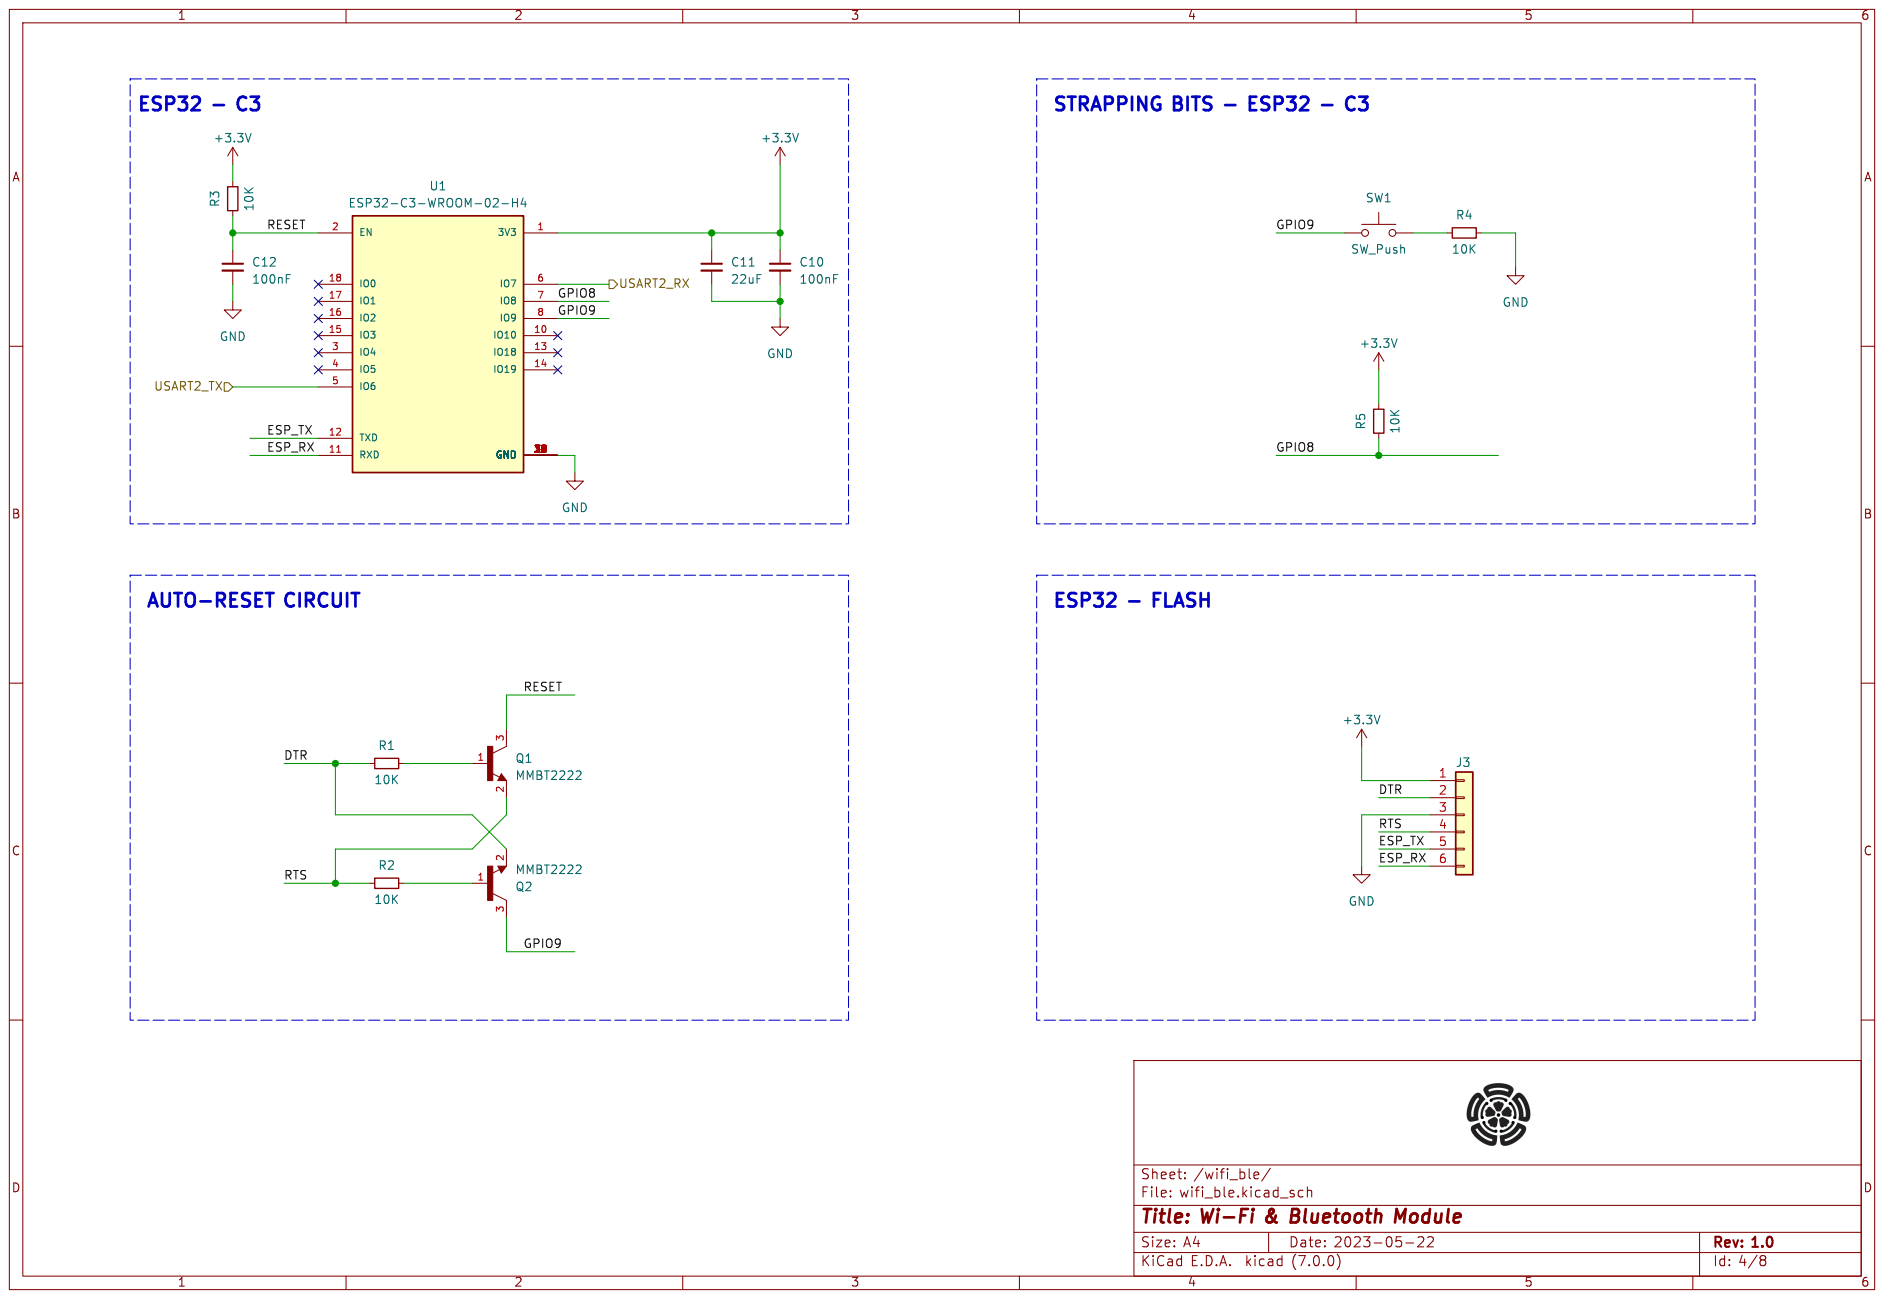
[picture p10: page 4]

File: wifi_ble.kicad_sch Sheet: /wifi_ble/
Id: 4/8 Title: Wi-Fi & Bluetooth Module

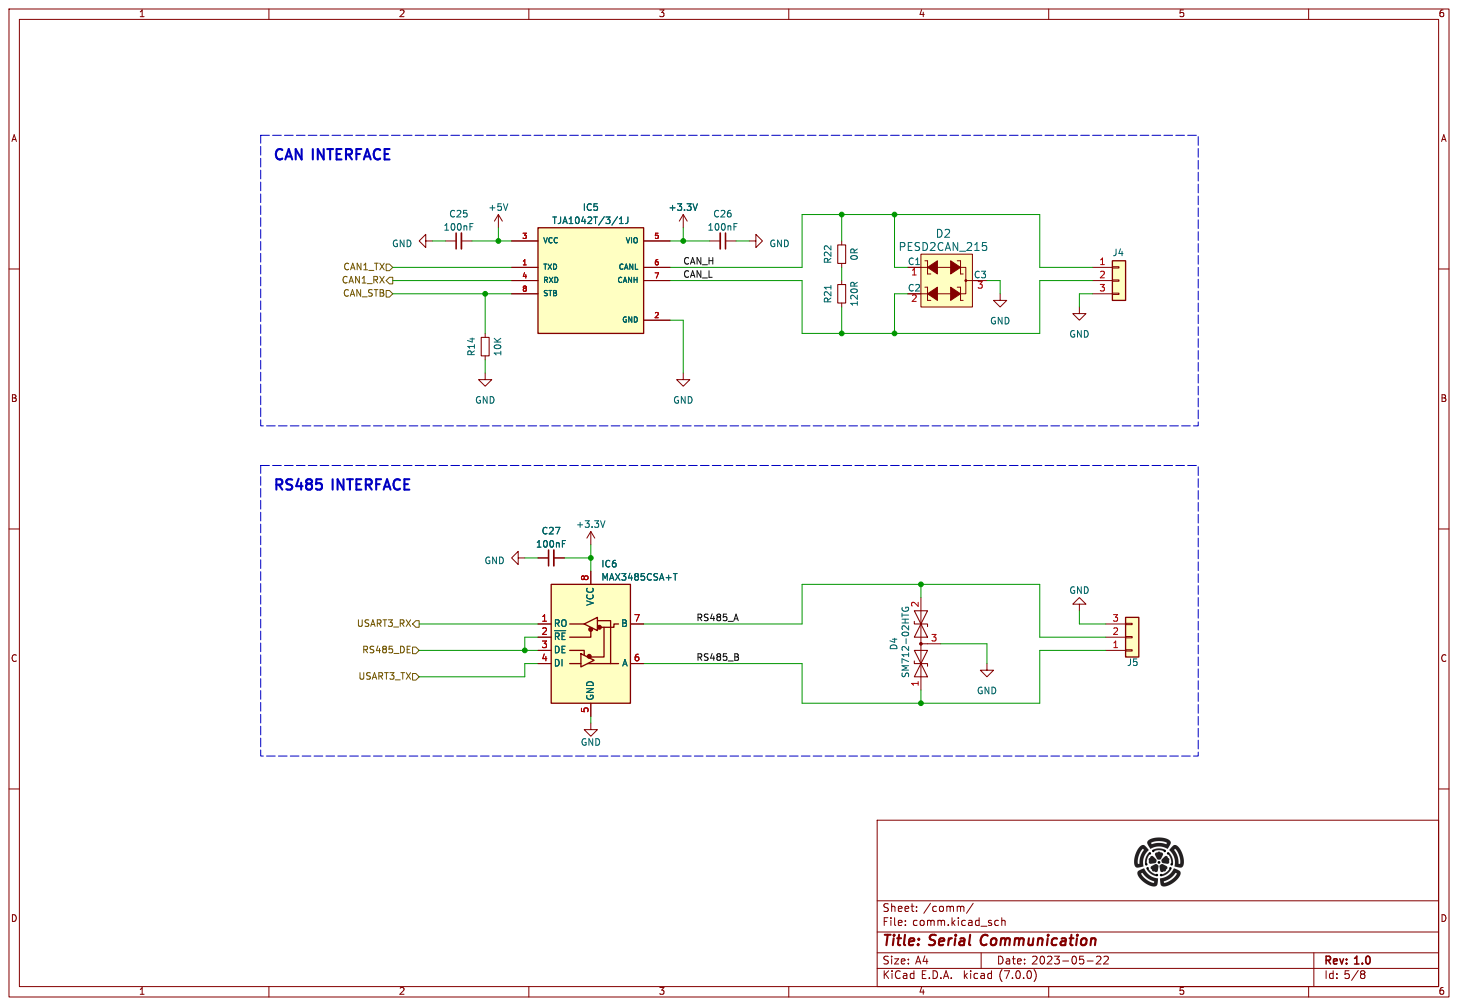
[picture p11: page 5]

File: comm.kicad_sch Sheet: /comm/
Id: 5/8 Title: Serial Communication

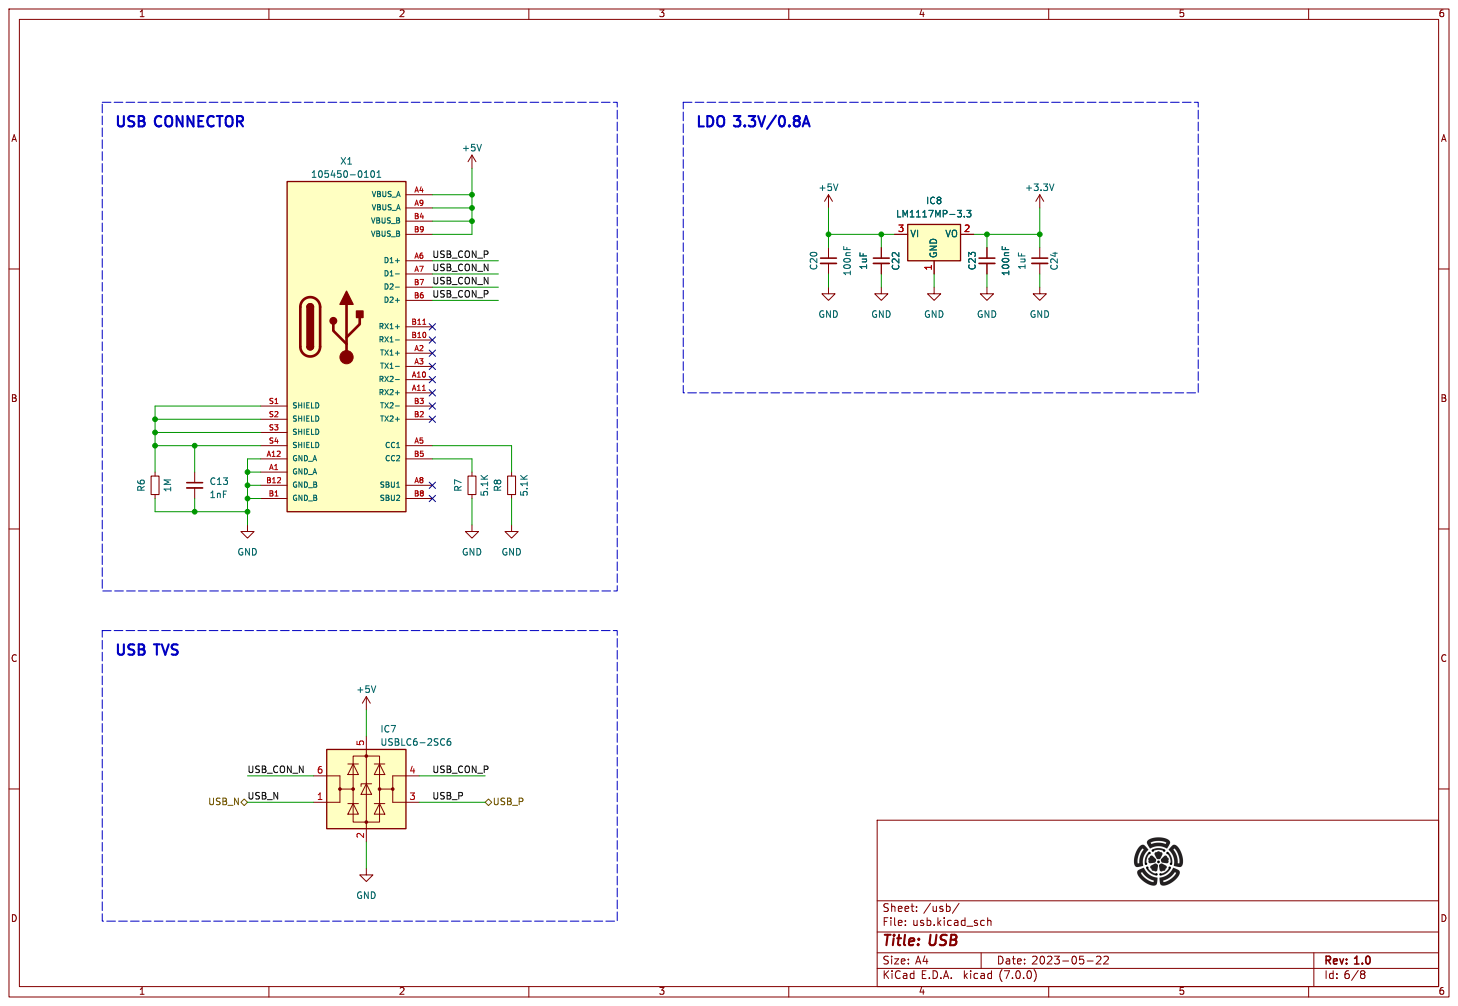
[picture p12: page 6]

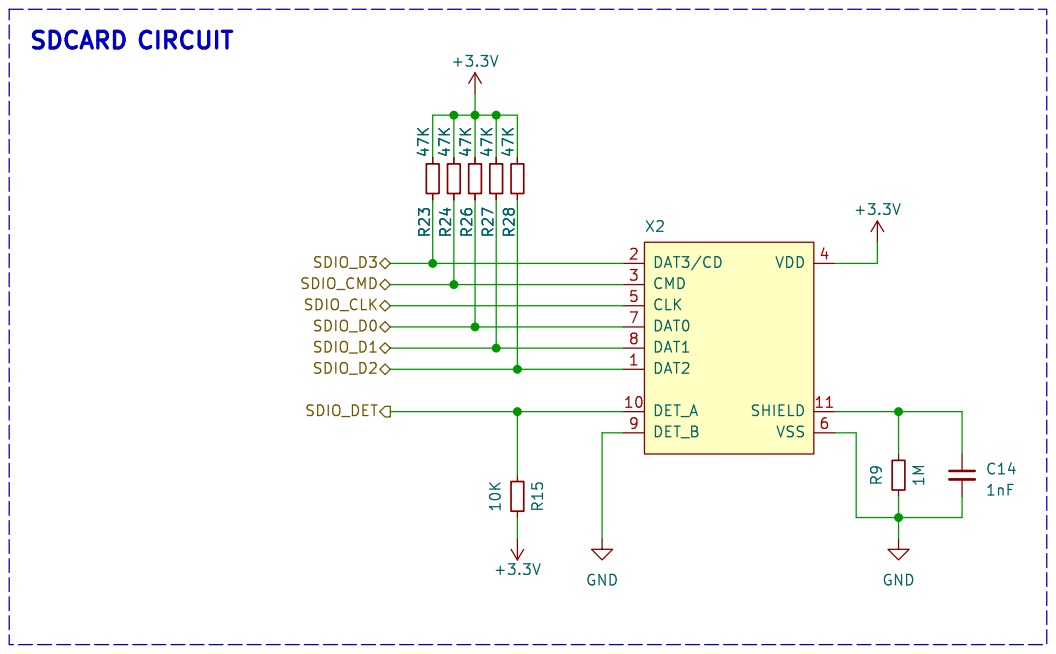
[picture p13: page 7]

File: sdcard.kicad_sch Sheet: /sdcard/ GND

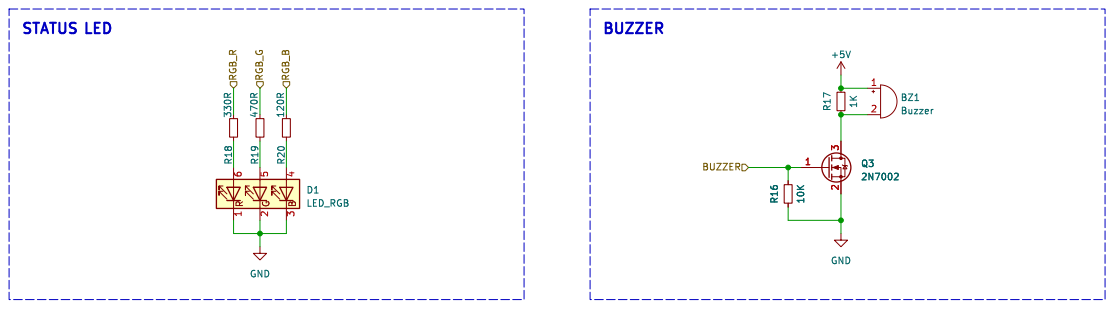
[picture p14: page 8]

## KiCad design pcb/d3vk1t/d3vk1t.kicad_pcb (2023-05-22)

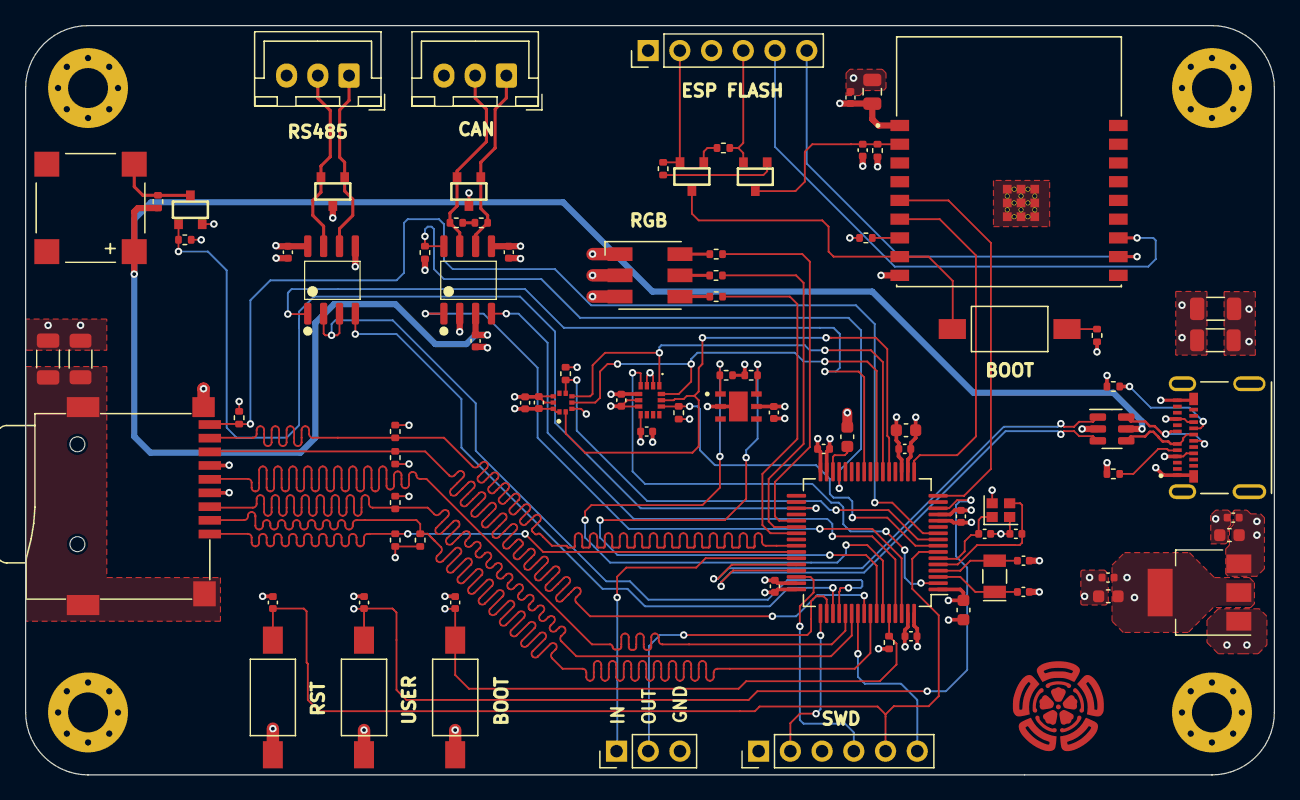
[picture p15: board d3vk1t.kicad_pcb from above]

Board: 4 copper layers, 100.0 x 60.0 mm, 93 parts (0 on the bottom side), 70 nets.

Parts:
BZ1: Buzzer; PUIAudio_SMT_0825_S_4_R
C1, C2, C3, C4, C5, C9, C10, C12, C15, C16, C17, C18, C19, C20, C21, C23, C25, C26, C27, C32: 100nF; C_0402_1005Metric
C6, C22, C24: 1uF; C_0603_1608Metric
C7: 4.7uF; C_0603_1608Metric
C8: 2.2uF; C_0603_1608Metric
C11: 22uF; C_0805_2012Metric
C13, C14: 1nF; C_1206_3216Metric
C28, C29: 20pF; C_0402_1005Metric
C30, C31: 6.8pF; C_0402_1005Metric
D1: LED_RGB; LED_RGB_5050-6
D2: PESD2CAN_215; SOT-23B
D4: SM712-02HTG; SOT-23B
H1, H2, H3, H4: MountingHole; MountingHole_3.2mm_M3_Pad_Via
IC1: STM32F412RET6; LQFP-64_10x10mm_P0.5mm
IC2: LSM6DSMTR; PQFN50P300X250X86-14N
IC3: HDC1080DMBR; SON100P300X300X80-7N
IC4: LPS22HBTR; PQFN50P200X200X80-10N
IC5: TJA1042T/3/1J; SOIC127P600X175-8N
IC6: MAX3485CSA+T; SOIC127P600X175-8N
IC7: USBLC6-2SC6; SOT-23-6
IC8: LM1117MP-3.3; SOT-223-3_TabPin2
J1: Conn_01x03; PinHeader_1x03_P2.54mm_Vertical
J2, J3: Conn_01x06; PinHeader_1x06_P2.54mm_Vertical
J4, J5: Conn_01x03; JST_XH_B3B-XH-A_1x03_P2.50mm_Vertical
Q1, Q2: MMBT2222; SOT-23B
Q3: 2N7002; SOT-23B
R1, R2, R3, R4, R5, R10, R11, R12, R13, R14, R15, R16, R25: 10K; R_0402_1005Metric
R6, R9: 1M; R_1206_3216Metric
R7, R8: 5.1K; R_0402_1005Metric
R17: 1K; R_0402_1005Metric
R18: 330R; R_0402_1005Metric
R19: 470R; R_0402_1005Metric
R20, R21: 120R; R_0402_1005Metric
R22: 0R; R_0402_1005Metric
R23, R24, R26, R27, R28: 47K; R_0402_1005Metric
SW1, SW2, SW3, SW4: SW_Push; SW_SPST_FSMSM
U1: ESP32-C3-WROOM-02-H4; MODULE_ESP32-C3-WROOM-02-H4
X1: 105450-0101; MOLEX_105450-0101
X2: Micro_SD_Card_Det; microSD_SOFNG_TF-015
Y1: 32.7680KHZ; Crystal_SMD_EuroQuartz_EQ161-2Pin_3.2x1.5mm
Y2: 24MHz; Crystal_SMD_2016-4Pin_2.0x1.6mm

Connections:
+3.3V: C1.1, C2.1, C3.1, C4.1, C5.1, C6.1, C7.1, C10.1, C11.1, C16.1, C17.1, C18.1, C19.1, C21.1, C23.1, C24.1, C26.2, C27.2, C32.2, IC1.1 (VBAT), IC1.13 (VDDA), IC1.19 (VDD), IC1.32 (VDD), IC1.48 (VDD), IC1.64 (VDD), IC2.5 (VDDIO), IC2.8 (VDD), IC3.5 (VDD), IC4.1 (VDD_IO), IC4.10 (VDD), IC5.5 (VIO), IC6.8 (VCC), IC8.2 (VO), J2.1, J3.1, R3.2, R5.2, R10.2, R11.2, R12.2, R13.2, R15.2, R23.2, R24.2, R26.2, R27.2, R28.2, SW4.1, U1.1 (3V3), X2.4 (VDD)
+5V: BZ1.1 (-), C20.1, C22.1, C25.2, IC5.3 (VCC), IC7.5 (VBUS), IC8.3 (VI), R17.2, X1.A4 (VBUS_A), X1.A9 (VBUS_A), X1.B4 (VBUS_B), X1.B9 (VBUS_B)
/comm/CAN1_RX: IC1.61 (PB8), IC5.4 (RXD)
/comm/CAN1_TX: IC1.62 (PB9), IC5.1 (TXD)
/comm/CAN_H: D2.1 (C1), IC5.6 (CANL), J4.1, R22.2
/comm/CAN_L: D2.2 (C2), IC5.7 (CANH), J4.2, R21.1
/comm/CAN_STB: IC1.29 (PB10), IC5.8 (STB), R14.2
/comm/RS485_A: D4.2 (A2), IC6.7 (B), J5.2
/comm/RS485_B: D4.1 (A1), IC6.6 (A), J5.1
/comm/RS485_DE: IC1.52 (PC11), IC6.2 (~RE), IC6.3 (DE)
/mcu/BOOT0: C32.1, IC1.60 (BOOT0), R25.2, SW4.2
/mcu/BUZZER: IC1.35 (PB14), Q3.1 (G), R16.2
/mcu/NRST: C9.1, IC1.7 (NRST), J2.5, SW2.2
/mcu/OSC32_IN: C30.1, IC1.3 (PC14), Y1.1
/mcu/OSC32_OUT: C31.1, IC1.4 (PC15), Y1.2
/mcu/OSC_IN: C28.1, IC1.5 (PH0), Y2.3
/mcu/OSC_OUT: C29.1, IC1.6 (PH1), Y2.1
/mcu/RGB_B: IC1.39 (PC8), R20.2
/mcu/RGB_G: IC1.38 (PC7), R19.2
/mcu/RGB_R: IC1.37 (PC6), R18.2
/mcu/SDIO_CLK: IC1.53 (PC12), X2.5 (CLK)
/mcu/SDIO_CMD: IC1.54 (PD2), R24.1, X2.3 (CMD)
/mcu/SDIO_D0: IC1.56 (PB4), R26.1, X2.7 (DAT0)
/mcu/SDIO_D1: IC1.41 (PA8), R27.1, X2.8 (DAT1)
/mcu/SDIO_D2: IC1.42 (PA9), R28.1, X2.1 (DAT2)
/mcu/SDIO_D3: IC1.57 (PB5), R23.1, X2.2 (DAT3/CD)
/mcu/SDIO_DET: IC1.10 (PC2), R15.1, X2.10 (DET_A)
/mcu/SWCLK: IC1.49 (PA14), J2.2
/mcu/SWDIO: IC1.46 (PA13), J2.4
/mcu/SWO: IC1.55 (PB3), J2.6
/mcu/USART1_RX: IC1.43 (PA10), J1.1
/mcu/USART1_TX: IC1.50 (PA15), J1.2
/mcu/USART2_RX: IC1.17 (PA3), U1.6 (IO7)
/mcu/USART2_TX: IC1.16 (PA2), U1.5 (IO6)
/mcu/USART3_RX: IC1.25 (PC5), IC6.1 (RO)
/mcu/USART3_TX: IC1.51 (PC10), IC6.4 (DI)
/mcu/USB_N: IC1.44 (PA11), IC7.1 (I/O1)
/mcu/USB_P: IC1.45 (PA12), IC7.3 (I/O2)
/mcu/USER: C15.1, IC1.14 (PA0), SW3.2
/sensors/ACC_CS: IC1.8 (PC0), IC2.12 (CS), R10.1
/sensors/ACC_INT: IC1.2 (PC13), IC2.4 (INT1)
/sensors/BARO_CS: IC1.9 (PC1), IC4.6 (CS), R11.1
/sensors/I2C1_SCL: IC1.58 (PB6), IC3.6 (SCL), R12.1
/sensors/I2C1_SDA: IC1.59 (PB7), IC3.1 (SDA), R13.1
/sensors/SPI1_CLK: IC1.21 (PA5), IC2.13 (SCL/SPC), IC4.2 (SCL/SPC)
/sensors/SPI1_MISO: IC1.22 (PA6), IC2.1 (SDO/SA0), IC4.5 (SDO/SA0)
/sensors/SPI1_MOSI: IC1.23 (PA7), IC2.14 (SDA/SDI/SDO), IC4.4 (SDA/SDI/SDO)
/usb/USB_CON_N: IC7.6 (I/O1), X1.A7 (D1-), X1.B7 (D2-)
/usb/USB_CON_P: IC7.4 (I/O2), X1.A6 (D1+), X1.B6 (D2+)
/wifi_ble/DTR: J3.2, Q2.2, R1.1
/wifi_ble/ESP_RX: J3.6, U1.11 (RXD)
/wifi_ble/ESP_TX: J3.5, U1.12 (TXD)
/wifi_ble/GPIO8: R5.1, U1.7 (IO8)
/wifi_ble/GPIO9: Q2.3, SW1.1, U1.8 (IO9)
/wifi_ble/RESET: C12.1, Q1.3, R3.1, U1.2 (EN)
/wifi_ble/RTS: J3.4, Q1.2, R2.1
GND: C1.2, C2.2, C3.2, C4.2, C5.2, C6.2, C7.2, C8.2, C9.2, C10.2, C11.2, C12.2, C13.2, C14.2, C15.2, C16.2, C17.2, C18.2, C19.2, C20.2, C21.2, C22.2, C23.2, C24.2, C25.1, C26.1, C27.1, C28.2, C29.2, C30.2, C31.2, D1.1 (RK), D1.2 (GK), D1.3 (BK), D2.3 (C3), D4.3 (common), IC1.12 (VSSA), IC1.18 (VSS), IC1.31 (VSS), IC1.47 (VSS), IC1.63 (VSS), IC2.2 (SDX), IC2.3 (SCX), IC2.6 (GND), IC2.7 (GND), IC3.2 (GND), IC3.7 (EXP), IC4.3 (RESERVED), IC4.8 (GND), IC4.9 (GND), IC5.2 (GND), IC6.5 (GND), IC7.2 (GND), IC8.1 (GND), J1.3, J2.3, J3.3, J4.3, J5.3, Q3.2 (S), R4.2, R6.1, R7.1, R8.1, R9.1, R14.1, R16.1, R25.1, SW2.1, SW3.1, U1.9 (GND), U1.19 (GND), U1.20 (GND), U1.21 (GND), U1.22 (GND), U1.23 (GND), U1.24 (GND), U1.25 (GND), U1.26 (GND), U1.27 (GND), U1.28 (GND), U1.29 (GND), U1.30 (GND), U1.31 (GND), U1.32 (GND), U1.33 (GND), U1.34 (GND), U1.35 (GND), U1.36 (GND), U1.37 (GND), U1.38 (GND), U1.39 (GND), X1.A1 (GND_A), X1.A12 (GND_A), X1.B1 (GND_B), X1.B12 (GND_B), X2.6 (VSS), X2.9 (DET_B), Y2.2, Y2.4
unnamed: BZ1.2 (+), Q3.3 (D), R17.1
unnamed: C13.1, R6.2, X1.S1 (SHIELD), X1.S2 (SHIELD), X1.S3 (SHIELD), X1.S4 (SHIELD)
unnamed: D1.4 (BA), R20.1
unnamed: D1.5 (GA), R19.1
unnamed: D1.6 (RA), R18.1
unnamed: C8.1, IC1.30 (VCAP_1)
unnamed: Q1.1, R1.2
unnamed: Q2.1, R2.2
unnamed: R4.1, SW1.2
unnamed: R21.2, R22.1
unnamed: R8.2, X1.A5 (CC1)
unnamed: R7.2, X1.B5 (CC2)
unnamed: C14.1, R9.2, X2.11 (SHIELD)

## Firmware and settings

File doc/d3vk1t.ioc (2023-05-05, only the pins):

Mcu.UserName=STM32F412RETx
PA0.GPIO_Label=USER_BTN
PA0.Signal=GPXTI0
PA10.Signal=USART1_RX
PA11.Signal=USB_OTG_FS_DM
PA12.Signal=USB_OTG_FS_DP
PA13.Signal=SYS_JTMS-SWDIO
PA14.Signal=SYS_JTCK-SWCLK
PA15.Signal=USART1_TX
PA2.Signal=USART2_TX
PA3.Signal=USART2_RX
PA5.Signal=SPI1_SCK
PA6.Signal=SPI1_MISO
PA7.Signal=SPI1_MOSI
PA8.Signal=SDIO_D1
PA9.Signal=SDIO_D2
PB10.GPIO_Label=CAN_STB
PB10.Signal=GPIO_Output
PB14.GPIO_Label=BUZZER
PB14.Signal=S_TIM12_CH1
PB3.Signal=SYS_JTDO-SWO
PB4.Signal=SDIO_D0
PB5.Signal=SDIO_D3
PB6.Signal=I2C1_SCL
PB7.Signal=I2C1_SDA
PB8.Signal=CAN1_RX
PB9.Signal=CAN1_TX
PC0.GPIO_Label=ACC_CS
PC0.Signal=GPIO_Output
PC1.GPIO_Label=BARO_CS
PC1.Signal=GPIO_Output
PC10.Signal=USART3_TX
PC11.GPIO_Label=RS485_DE
PC11.Signal=GPIO_Output
PC12.Signal=SDIO_CK
PC13.GPIO_Label=ACC_INT
PC13.Signal=GPXTI13
PC14-OSC32_IN.Signal=RCC_OSC32_IN
PC15-OSC32_OUT.Signal=RCC_OSC32_OUT
PC2.GPIO_Label=SD_DET
PC2.Signal=GPXTI2
PC5.Signal=USART3_RX
PC6.GPIO_Label=RGB_RED
PC6.Signal=S_TIM8_CH1
PC7.GPIO_Label=RGB_GREEN
PC7.Signal=S_TIM8_CH2
PC8.GPIO_Label=RGB_BLUE
PC8.Signal=S_TIM8_CH3
PD2.Signal=SDIO_CMD

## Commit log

2023-04-12 [pcb: define board shape]
    [comm.kicad_sch, d3vk1t.kicad_pcb, d3vk1t.kicad_sch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]
2023-04-13 [doc: update mcu pinout, pcb: update board shape]
    [d3vk1t.kicad_pcb, d3vk1t.kicad_sch, sensors.kicad_sch]
2023-04-14 doc: added f4 hw dev doc
    [d3vk1t.kicad_pcb, d3vk1t.kicad_sch, mcu.kicad_sch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]
2023-04-26 [update all schematics sheets]
    [comm.kicad_sch, d3vk1t.kicad_pcb, d3vk1t.kicad_sch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]
2023-05-05 sch: update all sch sheets.
    [comm.kicad_sch, d3vk1t.kicad_pcb, d3vk1t.kicad_sch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]
2023-05-16 pcb: update layout
    [comm.kicad_sch, d3vk1t.kicad_pcb, mcu.kicad_sch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]
2023-05-22 project update - update pcb layout. - update schmatics sheets. - added manufacturing files. - added documentation files.
    [comm.kicad_sch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]
2023-05-23 added interactive bom link
